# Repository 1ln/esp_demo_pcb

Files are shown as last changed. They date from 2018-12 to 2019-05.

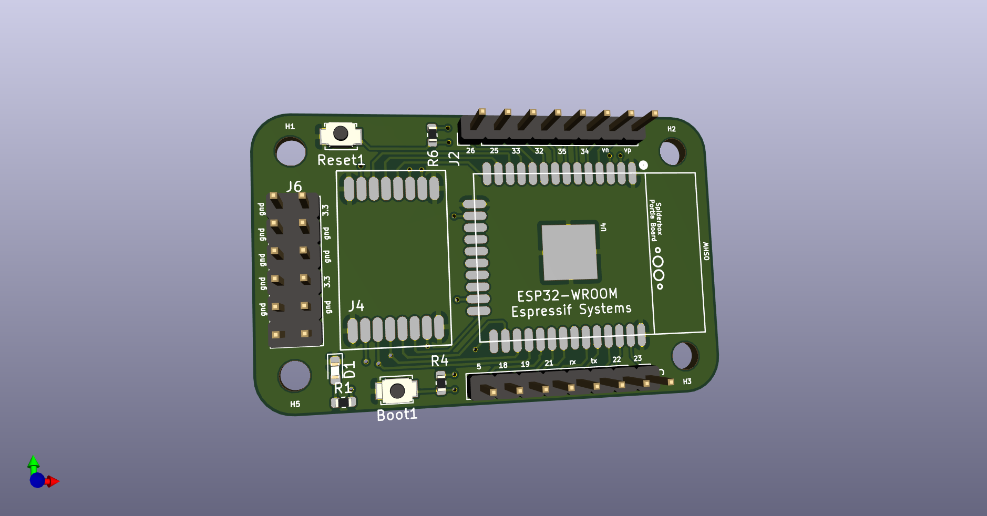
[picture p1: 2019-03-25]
3d.png

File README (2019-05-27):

Portia, Esp32 development board

Notice: Project is currently in development and has not been fully tested.

Copyright: OSHW

As an open source pcb, You choose to use at your own risk. 

You are free to use under the terms of OSHW, however if you are interested in producing this as a product it would be my preference to enjoy a royalty of any profits made and/or credit. Please don't hesitate to contact me if you are interested in producing this.

Developed by Dan Olson, 2019

This is a small, low cost development board for the ESP32 wroom module (16 GB version).

Features:

Both VSPI and HSPI have been routed to a single header.
Low noise LDO
One 3 pin rgb led for status alerts and testing.
Programming port includes a ground pin.

Please be aware that there is no usb on this board, it is meant to be programmed with an external adapter.

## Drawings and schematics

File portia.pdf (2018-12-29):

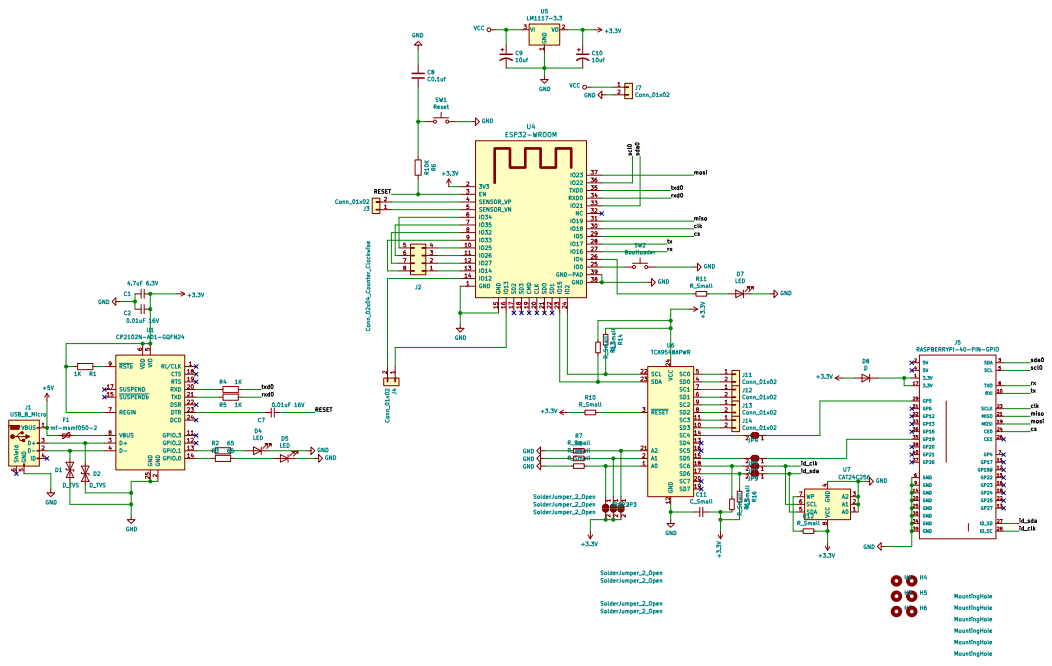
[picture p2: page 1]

6 REGIN 7 VBUS 8 RSTb 9 U1 CP2102N-A01-GQFN24 GND
J1 USB_B_Micro GND

2 RXD 20 TXD 21 DSR 22 DTR 23 DCD 24 GND 25 D+ 3 D- 4 VIO

4 SDA 5 SCL 6 WP 7 VCC

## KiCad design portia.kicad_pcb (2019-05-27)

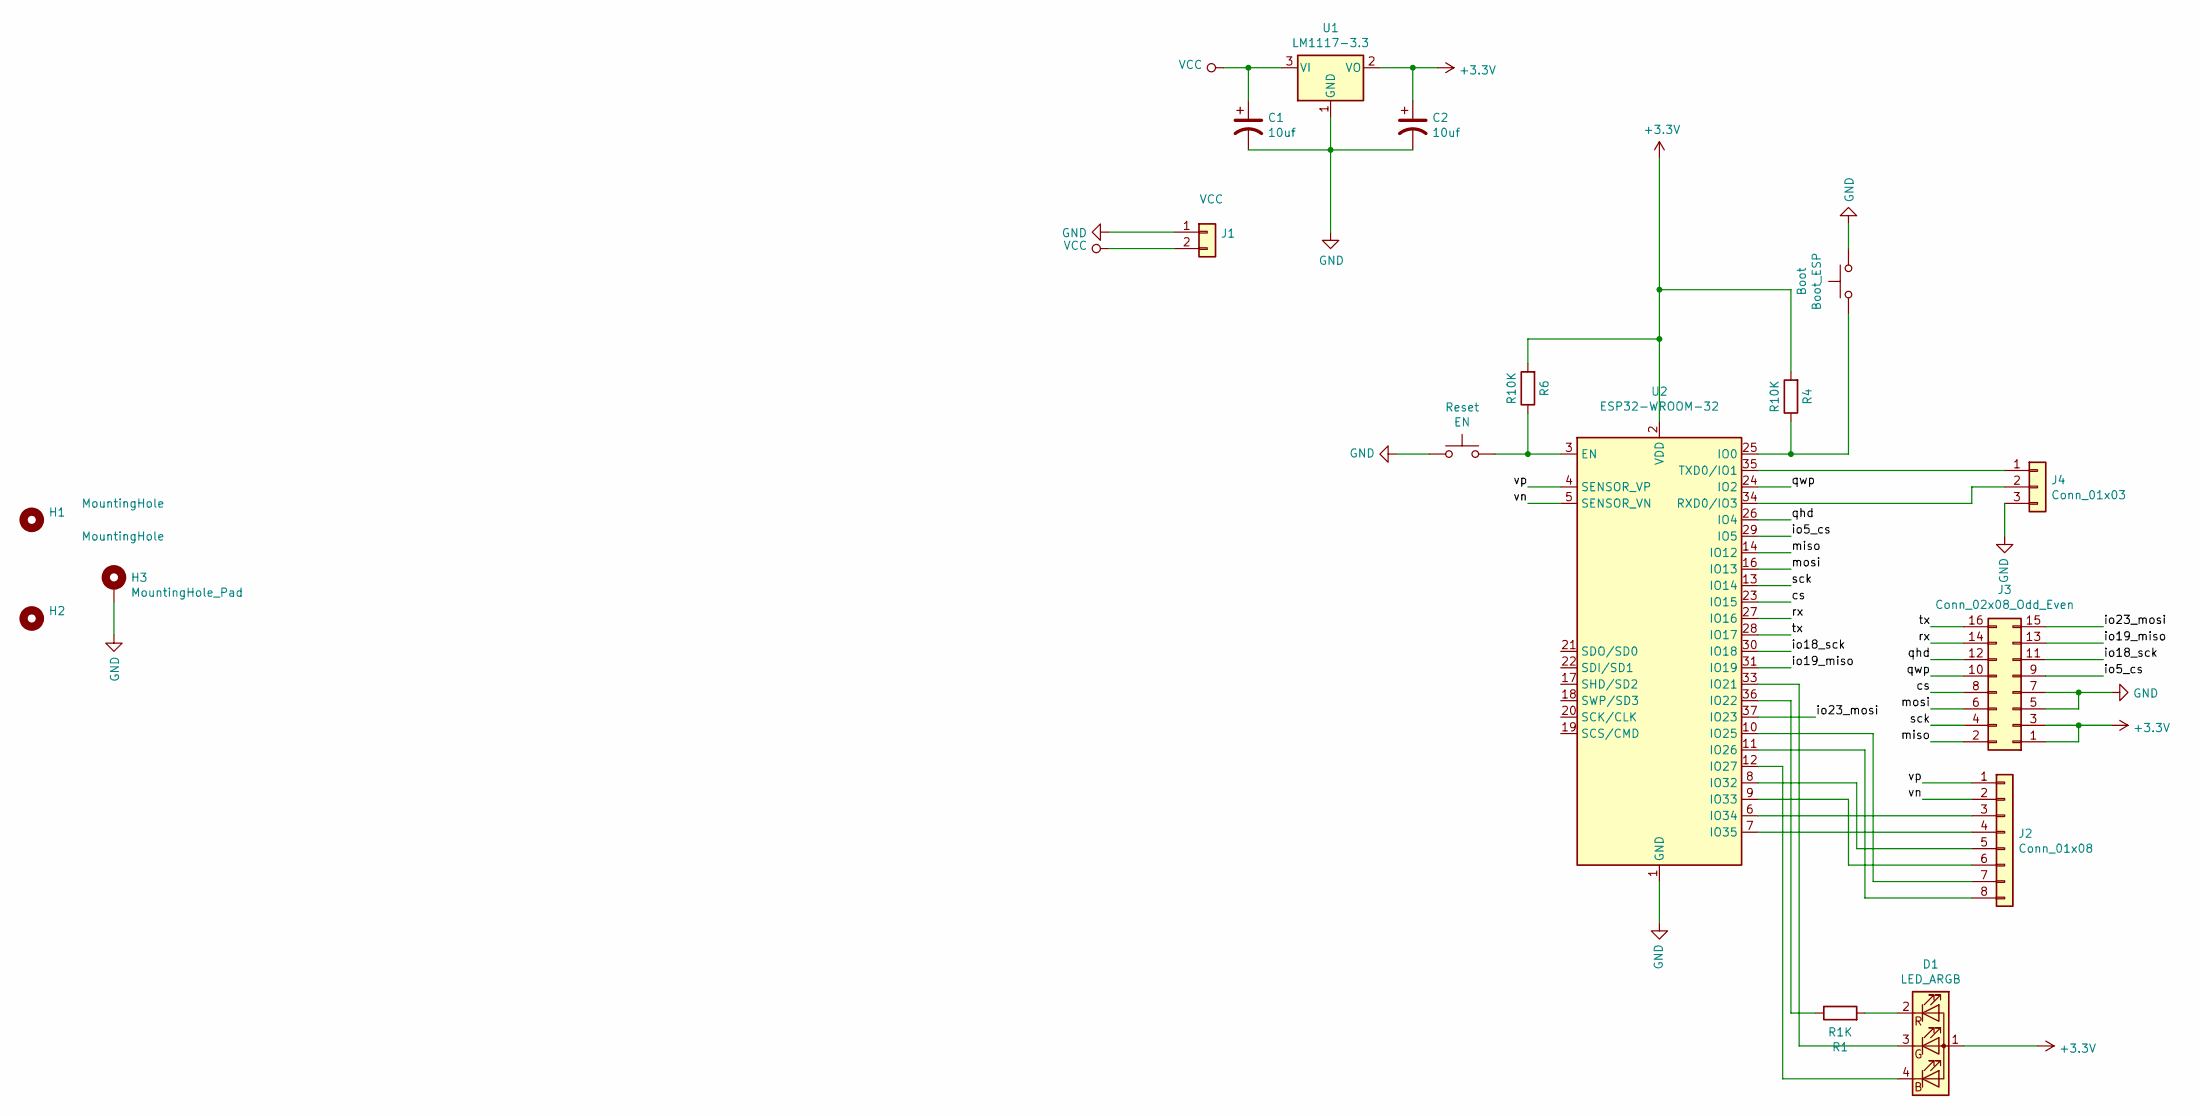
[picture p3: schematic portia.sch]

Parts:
Boot: Boot_ESP; SW_SPST_B3U-1000P-B
C1, C2: 10uf; C_0603_1608Metric_Pad1.05x0.95mm_HandSolder
D1: LED_ARGB; LED_RGB_5050-6
H1, H2: MountingHole; MountingHole_3mm
H3: MountingHole_Pad; MountingHole_3mm_Pad_Via
J1: VCC; PinHeader_1x02_P2.54mm_Vertical
J2: Conn_01x08; PinSocket_1x08_P2.54mm_Vertical
J3: Conn_02x08_Odd_Even; PinHeader_2x08_P2.54mm_Vertical
J4: Conn_01x03; PinHeader_1x03_P2.54mm_Vertical
R1: R1K; R_0603_1608Metric_Pad1.05x0.95mm_HandSolder
R4, R6: R10K; R_0603_1608Metric_Pad1.05x0.95mm_HandSolder
Reset: EN; SW_SPST_B3U-1000P-B
U1: LM1117-3.3; SOT-223
U2: ESP32-WROOM-32

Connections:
+3V3: C2.1, D1.1 (A), J3.1, J3.3, R4.2, R6.2, U1.2 (VO), U2.2 (VDD)
/cs: J3.8, U2.23 (IO15)
/io5_cs: J3.9, U2.29 (IO5)
/io18_sck: J3.11, U2.30 (IO18)
/io19_miso: J3.13, U2.31 (IO19)
/io23_mosi: J3.15, U2.37 (IO23)
/miso: J3.2, U2.14 (IO12)
/mosi: J3.6, U2.16 (IO13)
/qhd: J3.12, U2.26 (IO4)
/qwp: J3.10, U2.24 (IO2)
/rx: J3.14, U2.27 (IO16)
/sck: J3.4, U2.13 (IO14)
/tx: J3.16, U2.28 (IO17)
/vn: J2.2, U2.5 (SENSOR_VN)
/vp: J2.1, U2.4 (SENSOR_VP)
GND: Boot.2, C1.2, C2.2, H3.1, J1.1, J3.5, J3.7, J4.3, Reset.1, U1.1 (GND), U2.1 (GND), U2.15 (GND), U2.38 (GND)
unnamed: Boot.1, R4.1, U2.25 (IO0)
unnamed: D1.2 (RK), R1.2
unnamed: D1.3 (GK), U2.33 (IO21)
unnamed: D1.4 (BK), U2.12 (IO27)
unnamed: J2.3, U2.6 (IO34)
unnamed: J2.4, U2.7 (IO35)
unnamed: J2.5, U2.8 (IO32)
unnamed: J2.6, U2.9 (IO33)
unnamed: J2.7, U2.10 (IO25)
unnamed: J2.8, U2.11 (IO26)
unnamed: J4.1, U2.35 (TXD0/IO1)
unnamed: J4.2, U2.34 (RXD0/IO3)
unnamed: R1.1, U2.36 (IO22)
unnamed: R6.1, Reset.2, U2.3 (EN)
VCC: C1.1, J1.2, U1.3 (VI)

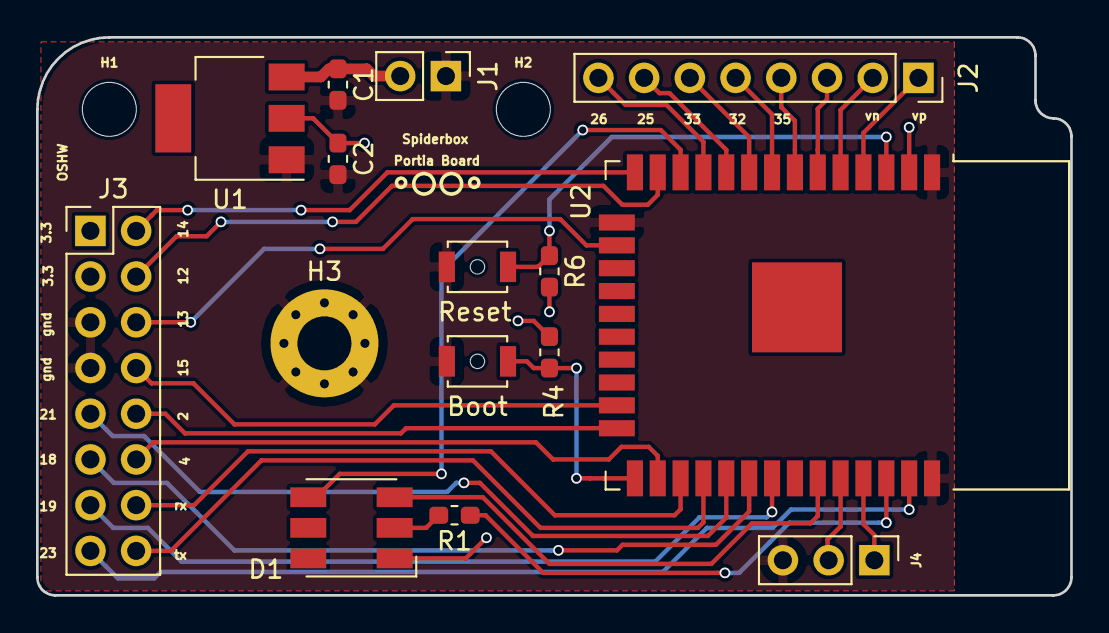
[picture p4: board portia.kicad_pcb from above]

Board: 2 copper layers, 57.4 x 31.0 mm, 17 parts (0 on the bottom side), 31 nets.

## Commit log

2018-11-13 inital commit
    [esp32_io_board.kicad_pcb, esp32_io_board.sch]
2018-11-29 usb bus cp1202n
    [esp32_io_board.sch]
2018-12-16 removed 3 sx1509 chips
    [esp32_io_board.sch]
2018-12-18 modified design
    [esp32_io_board.sch]
2018-12-21 rgb addressable led indication
    [esp32_io_board.sch]
2018-12-22 spi ports
    [esp32_io_board.sch]
2018-12-22 final schematic
    [esp32_io_board.sch]
2018-12-22 reset on dtr
    [esp32_io_board.sch]
2018-12-22 power pins added on txb104
    [esp32_io_board.sch]
2018-12-22 initial import
    [esp32_io_board.kicad_pcb]
2018-12-22 initial layout without traces
    [esp32_io_board.sch]
2018-12-24 raspberry pi integration
    [_saved_esp32_io_board.sch, esp32_io_board.kicad_pcb, esp32_io_board.sch]
2018-12-25 i2c jumpers
    [esp32_io_board.sch]
2018-12-26 layout update
    [esp32_io_board.kicad_pcb, esp32_io_board.sch]
2018-12-26 layout design
    [esp32_io_board.kicad_pcb]
2018-12-29 pcb final layout adjustments
    [esp32_io_board.kicad_pcb]
2019-01-02 modified trace connections
    [portia.kicad_pcb, portia.sch]
2019-01-02 resolved routing issue
    [portia.kicad_pcb, portia.sch]
2019-01-03 redesign removed 40 pin header
    [portia.kicad_pcb, portia.sch]
2019-01-04 redesigned i2c bus
    [portia.kicad_pcb]
2019-01-04 removed extra trace
    [portia.kicad_pcb]
2019-01-04 updated schematic redesign
    [portia.sch]
2019-01-05 adding new layout components
    [portia.kicad_pcb]
2019-01-05 redesign layout sensors
    [portia.kicad_pcb, portia.sch]
2019-01-06 ground plane fill
    [portia-B.Cu.gbl, portia-B.Mask.gbs, portia-B.Paste.gbp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]
2019-01-06 updated png
    [portia.kicad_pcb]
2019-01-07 added ground ports
    [portia.kicad_pcb, portia.sch]
2019-01-10 fix i2c net list +3V3
    [portia.kicad_pcb, portia.sch]
2019-01-10 add unconnected ground esp32
    [portia.kicad_pcb, portia.sch]
2019-01-12 modify reference designators
    [portia.kicad_pcb]
2019-01-12 modify pad properties
    [portia.kicad_pcb]
2019-01-12 add name of board
    [portia.kicad_pcb]
2019-01-12 add ground
    [portia.kicad_pcb, portia.sch]
2019-01-12 board design complete
    [portia.kicad_pcb]
2019-01-12 modify silkscreen
    [portia.kicad_pcb]
2019-01-24 update redesign add esp32
    [esp32_io_board-B.Cu.gbl, esp32_io_board-B.Mask.gbs, esp32_io_board-B.Paste.gbp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]
2019-01-24 update esp32 samd51 redesign
    [esp32_io_board-B.Cu.gbl, esp32_io_board-B.Mask.gbs, esp32_io_board-B.Paste.gbp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]
2019-01-26 add power schematic samd51d
    [portia.sch]
2019-01-26 add transient tvs usb
    [portia.sch]
2019-01-26 update layout
    [portia.kicad_pcb, portia.sch]
2019-01-27 add initial schematic
    [portia.kicad_pcb, portia.sch]
2019-01-27 removed esd
    [portia.kicad_pcb, portia.sch]
2019-02-23 update schematic
    [portia.kicad_pcb, portia.sch]
2019-02-25 layout redesign
    [portia.kicad_pcb, portia.sch]
2019-02-27 add castellated footprint
    [portia.kicad_pcb, portia.sch]
2019-03-07 add traces
    [portia.kicad_pcb]
2019-03-25 update gerber
    [esp32_io_board-B.Cu.gbl, esp32_io_board-B.Mask.gbs, esp32_io_board-B.Paste.gbp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]
2019-03-26 update design
    [portia.kicad_pcb, portia.sch]
2019-05-22 update redesign
    [portia.kicad_pcb, portia.sch]
2019-05-27 update pcb
    [portia.kicad_pcb, portia.sch]
